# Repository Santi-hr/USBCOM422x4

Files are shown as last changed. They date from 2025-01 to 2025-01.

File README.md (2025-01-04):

# USBCOM422x4
Simple 4 channel USB to RS422 serial converter module board, based on the XR21B1424 USB UART Bridge.
When connected to a PC four virtual COM ports are available for communication with serial devices.

The board is inspired on a similar RS422 converter, but more robust and with updated functionalities:
* A more modern USB-C connector
* A newer, compact and more robust USB-Serial bridge IC
  * Includes ±15kV ESD on USB lines
  * Internally provides all necessary functionality (48MHz clock, regulator, drivers) which simplifies the design and minimizes component failures.
* A sightly more protected power input using a TVS, a PPTC and an improved LDO.
* Supports USB suspend mode, disabling the transceivers when no USB bus activity is detected.
* Pinout printed on bottom silkscreen. 

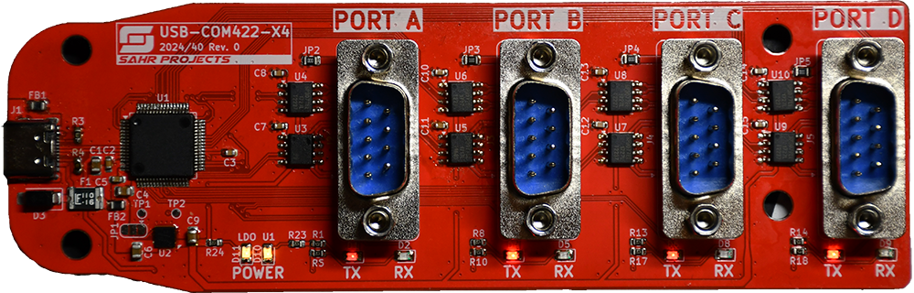
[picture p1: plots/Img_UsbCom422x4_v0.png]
Board picture


## Drivers
The USB Bridge chip can use the native OS CDC-ACM.
However, using the MaxLinear supplied custom drivers is recommended.

Get the latest drivers from their web, under "Documentation & Design Tools":
https://www.maxlinear.com/product/interface/uarts/usb-uarts/xr21b1424

A copy of the drivers used to test the board can be found in the [drivers](drivers) folder.

## Technical details

### Pinout
### USB
Standard 16 pin USB-C connector for use as a USB 2.0 full speed device (MBs).

### RS422 Serial port

Each serial port interface uses a DE-9 male connector.

| Pin | Signal | Direction | Description |
|-----|---|---|---|
| 1 | TX- | O | Data output, negative |
| 2 | TX+ | O | Data output, positive |
| 3 | RX+ | I | Data input, positive |
| 4 | RX- | I | Data input, negative |
| 5 | GND | - | Signal ground |
| 6 | RTS-  | O | Ready to send, negative |
| 7 | RTS+  | O | Ready to send, positive |
| 8 | CTS+  | I | Clear to send, positive |
| 9 | CTS-  | I | Clear to send, negative |

### HMI

| LED | Color  | Meaning |
|---|---|---|
| POWER LDO | Yellow | On when power is being provided to RS422 transceivers. Should be on when not in suspend mode. |
| POWER U1  | Yellow | On when USB-UART Bridge chip is powered. Should be always with the USB cable plugged |
| TX | Red | Led toggles at a rate of approximately 10 Hz whenever the corresponding UART transmit pin is active |
| RX | Green  | Led toggles at a rate of approximately 10 Hz whenever the corresponding UART receive pin is active  |

### Mechanical

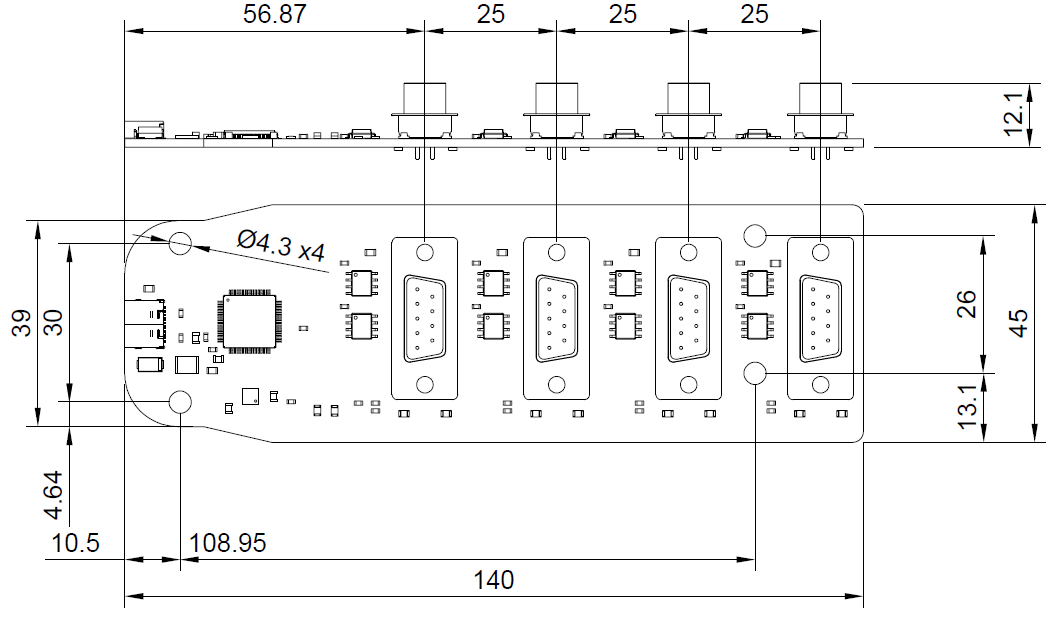
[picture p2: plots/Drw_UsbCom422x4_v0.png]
Board mechanical drawing

Dimensions in mm.

## Design notes

This board currently has not been tested for EMI/EMC compliance. Could generate or be affected by radio interferences.

The design only uses two layers in order to reduce manufacturing costs.
To get a cleaner layout and reduce possible EMI effects the stackup can be increased to 4 layers. 
Also size could be optimized and reduced, the current form factor follows the board I was trying to replace.

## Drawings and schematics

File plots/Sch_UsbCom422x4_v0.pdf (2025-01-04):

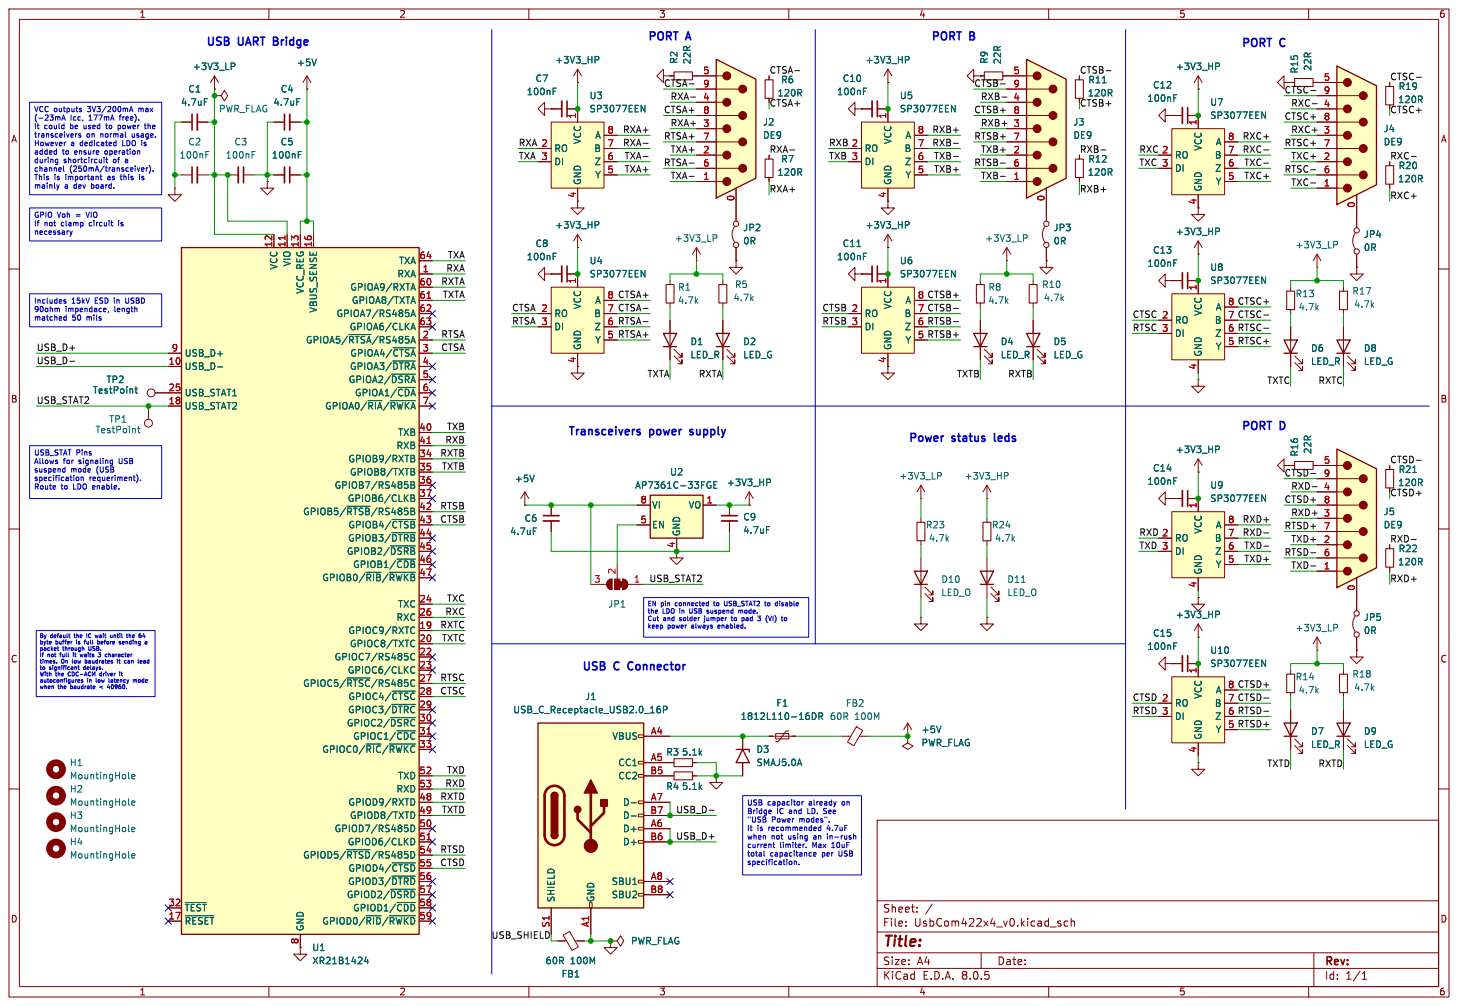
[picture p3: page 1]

It could be used to power the

TXA- TXA+ RXA- TXTC

GPIOA1/~{CDA}6 GPIOA9/RXTA 60 GPIOA8/TXTA 61 GPIOA7/RS485A 62 GPIOA6/CLKA 63 TXA 64 GPIOA0/~{RIA}/~{RWKA} 7 GND

TXD+ RTSD+ RXD+ RXTA CTSD

the LDO in USB suspend mode. Cut and solder jumper to pad 3 (VI) to

If not full it waits 3 character
4.7k H3 MountingHole

Id: 1/1 Title: File: UsbCom422x4_v0.kicad_sch Sheet: /

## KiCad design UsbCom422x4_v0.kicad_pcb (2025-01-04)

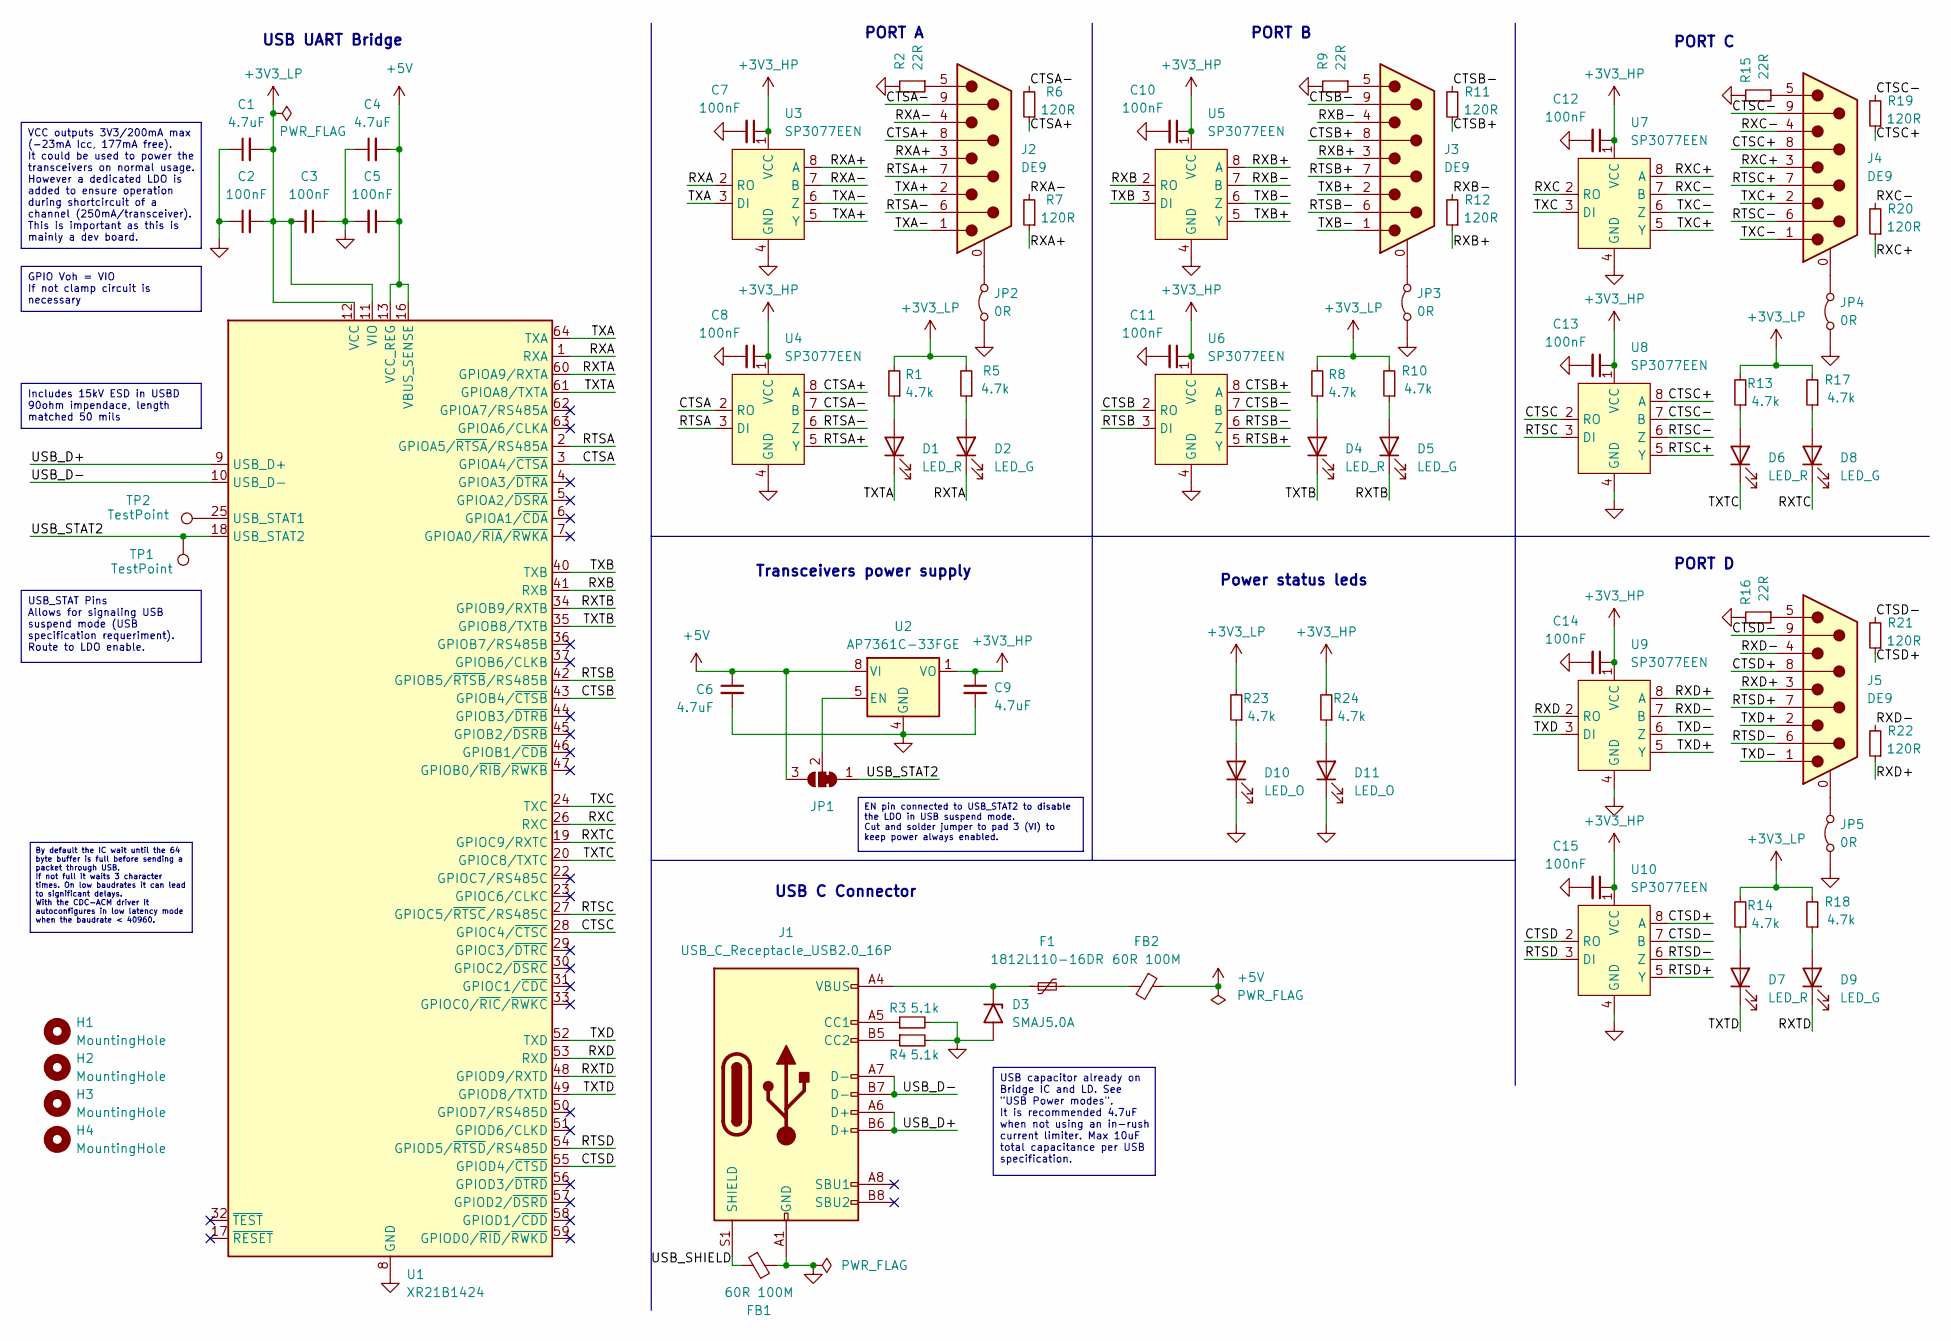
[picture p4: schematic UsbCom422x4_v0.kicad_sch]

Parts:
C1, C4, C6, C9: 4.7uF; C_0805_2012Metric
C2, C3, C5, C7, C8, C10, C11, C12, C13, C14, C15: 100nF; C_0603_1608Metric
D1, D4, D6, D7: LED_R; LED_0805_2012Metric
D2, D5, D8, D9: LED_G; LED_0805_2012Metric
D3: SMAJ5.0A; D_SMA
D10, D11: LED_O; LED_0805_2012Metric
F1: 1812L110-16DR; R_1812_4532Metric
FB1, FB2: 60R 100M; R_0805_2012Metric
H1, H2, H3, H4: MountingHole; MountingHole_4.3mm_M4
J1: USB_C_Receptacle_USB2.0_16P; USB_C_Receptacle_GCT_USB4105-xx-A_16P_TopMnt_Horizontal
J2, J3, J4, J5: DE9; DSUB-9_Male_Vertical_P2.77x2.84mm_MountingHoles
JP1: SolderJumper_3_Bridged12; SolderJumper-3_P1.3mm_Bridged12_RoundedPad1.0x1.5mm
JP2, JP3, JP4, JP5: 0R; R_0805_2012Metric
R1, R5, R8, R10, R13, R14, R17, R18, R23, R24: 4.7k; R_0603_1608Metric
R2, R9, R15, R16: 22R; R_0805_2012Metric
R3, R4: 5.1k; R_0603_1608Metric
R6, R7, R11, R12, R19, R20, R21, R22: 120R; R_1206_3216Metric
TP1, TP2: TestPoint; TestPoint_Pad_D1.0mm
U1: XR21B1424; LQFP-64_10x10mm_P0.5mm
U2: AP7361C-33FGE; U-DFN3030-8_AP7361C
U3, U4, U5, U6, U7, U8, U9, U10: SP3077EEN; SOIC-8_3.9x4.9mm_P1.27mm

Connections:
+3V3_HP: C7.1, C8.1, C9.1, C10.1, C11.1, C12.1, C13.1, C14.1, C15.1, R24.2, U2.1 (VO), U3.1 (VCC), U4.1 (VCC), U5.1 (VCC), U6.1 (VCC), U7.1 (VCC), U8.1 (VCC), U9.1 (VCC), U10.1 (VCC)
+3V3_LP: C1.2, C2.2, C3.2, R1.2, R5.2, R8.2, R10.2, R13.2, R14.2, R17.2, R18.2, R23.2, U1.11 (VIO), U1.12 (VCC), U1.38 (VIO)
+5V: C4.2, C5.1, C6.1, FB2.1, JP1.3 (B), U1.13 (VCC_REG), U1.16 (VBUS_SENSE), U2.8 (VI)
/CTSA: U1.3 (GPIOA4/~CTSA), U4.2 (RO)
/CTSA+: J2.8, R6.1, U4.8 (A)
/CTSA-: J2.9, R6.2, U4.7 (B)
/CTSB: U1.43 (GPIOB4/~CTSB), U6.2 (RO)
/CTSB+: J3.8, R11.1, U6.8 (A)
/CTSB-: J3.9, R11.2, U6.7 (B)
/CTSC: U1.28 (GPIOC4/~CTSC), U8.2 (RO)
/CTSC+: J4.8, R19.1, U8.8 (A)
/CTSC-: J4.9, R19.2, U8.7 (B)
/CTSD: U1.55 (GPIOD4/~CTSD), U10.2 (RO)
/CTSD+: J5.8, R21.1, U10.8 (A)
/CTSD-: J5.9, R21.2, U10.7 (B)
/RTSA: U1.2 (GPIOA5/~RTSA/RS485A), U4.3 (DI)
/RTSA+: J2.7, U4.5 (Y)
/RTSA-: J2.6, U4.6 (Z)
/RTSB: U1.42 (GPIOB5/~RTSB/RS485B), U6.3 (DI)
/RTSB+: J3.7, U6.5 (Y)
/RTSB-: J3.6, U6.6 (Z)
/RTSC: U1.27 (GPIOC5/~RTSC/RS485C), U8.3 (DI)
/RTSC+: J4.7, U8.5 (Y)
/RTSC-: J4.6, U8.6 (Z)
/RTSD: U1.54 (GPIOD5/~RTSD/RS485D), U10.3 (DI)
/RTSD+: J5.7, U10.5 (Y)
/RTSD-: J5.6, U10.6 (Z)
/RXA: U1.1 (RXA), U3.2 (RO)
/RXA+: J2.3, R7.1, U3.8 (A)
/RXA-: J2.4, R7.2, U3.7 (B)
/RXB: U1.41 (RXB), U5.2 (RO)
/RXB+: J3.3, R12.1, U5.8 (A)
/RXB-: J3.4, R12.2, U5.7 (B)
/RXC: U1.26 (RXC), U7.2 (RO)
/RXC+: J4.3, R20.1, U7.8 (A)
/RXC-: J4.4, R20.2, U7.7 (B)
/RXD: U1.53 (RXD), U9.2 (RO)
/RXD+: J5.3, R22.1, U9.8 (A)
/RXD-: J5.4, R22.2, U9.7 (B)
/RXTA: D2.1 (K), U1.60 (GPIOA9/RXTA)
/RXTB: D5.1 (K), U1.34 (GPIOB9/RXTB)
/RXTC: D8.1 (K), U1.19 (GPIOC9/RXTC)
/RXTD: D9.1 (K), U1.48 (GPIOD9/RXTD)
/TXA: U1.64 (TXA), U3.3 (DI)
/TXA+: J2.2, U3.5 (Y)
/TXA-: J2.1, U3.6 (Z)
/TXB: U1.40 (TXB), U5.3 (DI)
/TXB+: J3.2, U5.5 (Y)
/TXB-: J3.1, U5.6 (Z)
/TXC: U1.24 (TXC), U7.3 (DI)
/TXC+: J4.2, U7.5 (Y)
/TXC-: J4.1, U7.6 (Z)
/TXD: U1.52 (TXD), U9.3 (DI)
/TXD+: J5.2, U9.5 (Y)
/TXD-: J5.1, U9.6 (Z)
/TXTA: D1.1 (K), U1.61 (GPIOA8/TXTA)
/TXTB: D4.1 (K), U1.35 (GPIOB8/TXTB)
/TXTC: D6.1 (K), U1.20 (GPIOC8/TXTC)
/TXTD: D7.1 (K), U1.49 (GPIOD8/TXTD)
/USB_D+: J1.A6 (D+), J1.B6 (D+), U1.9 (USB_D+)
/USB_D-: J1.A7 (D-), J1.B7 (D-), U1.10 (USB_D-)
/USB_SHIELD: FB1.1, J1.S1 (SHIELD)
/USB_STAT2: JP1.1 (A), TP1.1, U1.18 (USB_STAT2)
GND: C1.1, C2.1, C3.1, C4.1, C5.2, C6.2, C7.2, C8.2, C9.2, C10.2, C11.2, C12.2, C13.2, C14.2, C15.2, D3.2 (A2), D10.1 (K), D11.1 (K), FB1.2, J1.A1 (GND), J1.A12 (GND), J1.B1 (GND), J1.B12 (GND), JP2.1 (A), JP3.1 (A), JP4.1 (A), JP5.1 (A), R2.2, R3.2, R4.2, R9.2, R15.2, R16.2, U1.8 (GND), U1.14 (GND), U1.15 (GND), U1.21 (GND), U1.39 (GND), U2.4 (GND), U2.9 (GND), U3.4 (GND), U4.4 (GND), U5.4 (GND), U6.4 (GND), U7.4 (GND), U8.4 (GND), U9.4 (GND), U10.4 (GND)
unnamed: D1.2 (A), R1.1
unnamed: D2.2 (A), R5.1
unnamed: D3.1 (A1), F1.1, J1.A4 (VBUS), J1.A9 (VBUS), J1.B4 (VBUS), J1.B9 (VBUS)
unnamed: D4.2 (A), R8.1
unnamed: D5.2 (A), R10.1
unnamed: D6.2 (A), R13.1
unnamed: D7.2 (A), R14.1
unnamed: D8.2 (A), R17.1
unnamed: D9.2 (A), R18.1
unnamed: D10.2 (A), R23.1
unnamed: D11.2 (A), R24.1
unnamed: F1.2, FB2.2
unnamed: J1.A5 (CC1), R3.1
unnamed: J1.B5 (CC2), R4.1
unnamed: J2.0 (PAD), JP2.2 (B)
unnamed: J2.5, R2.1
unnamed: J3.0 (PAD), JP3.2 (B)
unnamed: J3.5, R9.1
unnamed: J4.0 (PAD), JP4.2 (B)
unnamed: J4.5, R15.1
unnamed: J5.0 (PAD), JP5.2 (B)
unnamed: J5.5, R16.1
unnamed: JP1.2 (C), U2.5 (EN)
unnamed: TP2.1, U1.25 (USB_STAT1)

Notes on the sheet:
EN pin connected to USB_STAT2 to disable the LDO in USB suspend mode. Cut and solder jumper to pad 3 (VI) to keep power always enabled.
USB_STAT Pins Allows for signaling USB suspend mode (USB specification requeriment). Route to LDO enable.
USB capacitor already on Bridge IC and LD. See "USB Power modes". It is recommended 4.7uF when not using an in-rush current limiter. Max 10uF total capacitance per USB specification.
By default the IC wait until the 64 byte buffer is full before sending a packet through USB. If not full it waits 3 character times. On low baudrates it can lead to significant delays. With the CDC-ACM driver it autoconfigures in low latency mode when the baudrate < 40960.
VCC outputs 3V3/200mA max (-23mA Icc, 177mA free). It could be used to power the transceivers on normal usage. However a dedicated LDO is added to ensure operation during shortcircuit of a channel (250mA/transceiver). This is important as this is mainly a dev board.
Includes 15kV ESD in USBD 90ohm impendace, length matched 50 mils
GPIO Voh = VIO If not clamp circuit is necessary
PORT D
PORT B
PORT A
USB UART Bridge
Power status leds
Transceivers power supply
PORT C
USB C Connector

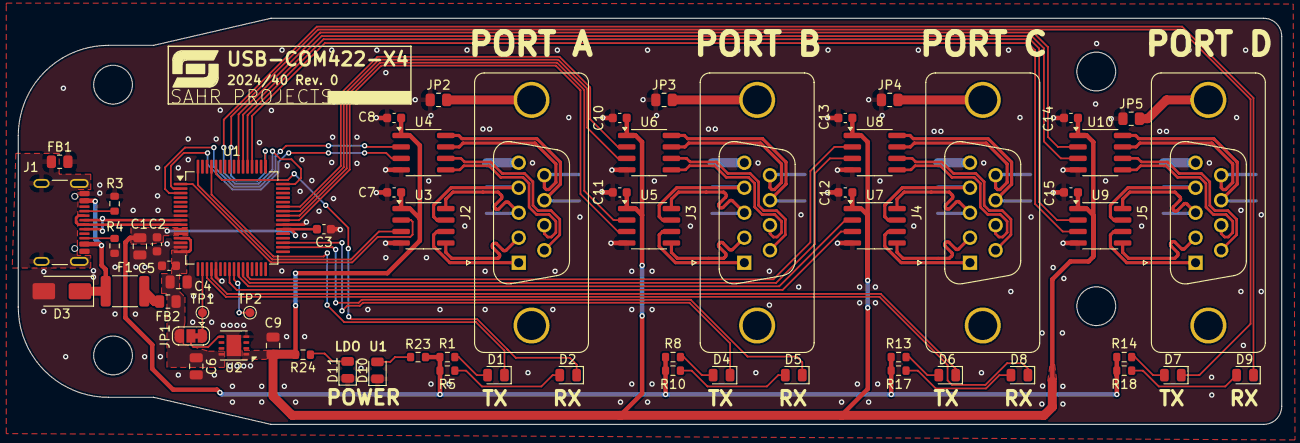
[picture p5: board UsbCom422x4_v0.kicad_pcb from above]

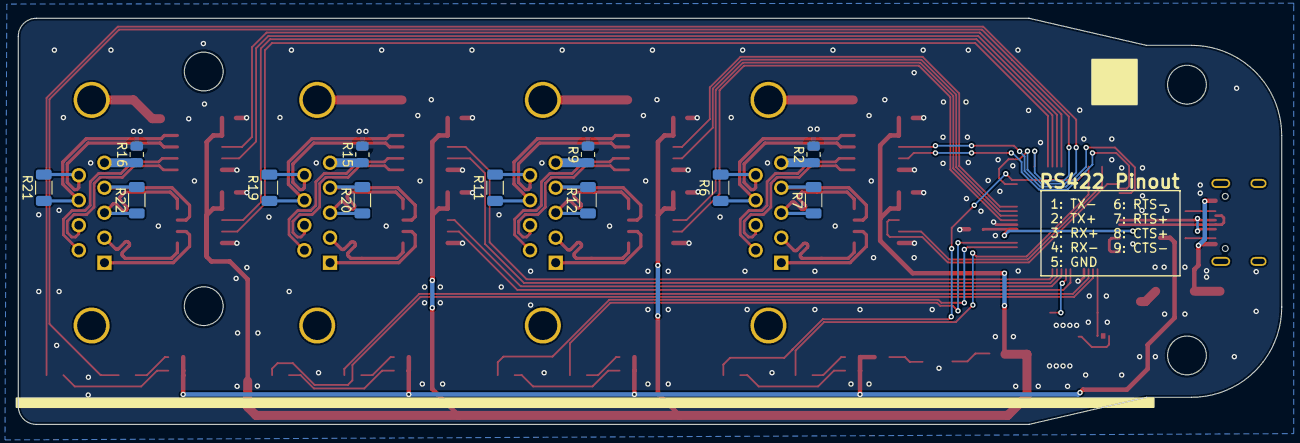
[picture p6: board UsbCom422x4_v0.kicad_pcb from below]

Board: 2 copper layers, 140.0 x 45.0 mm, 79 parts (12 on the bottom side), 88 nets.
